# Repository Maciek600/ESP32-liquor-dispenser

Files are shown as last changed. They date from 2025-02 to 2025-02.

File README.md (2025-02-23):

# ESP32 Alcohol Dispenser with Scale
### The goal of the project was to create a beverage dispenser with a built-in scale that precisely controls the amount of liquid poured. The device automatically dispenses the user-specified amount of liquid, measured based on the weight of the cup or glass. The user places a glass on a base with an integrated scale (load cell). When the distance sensor detects the presence of a glass, the scale resets, and the user selects the desired amount of beverage using a control panel with buttons. After confirmation, the device automatically starts pouring, continuously monitoring the weight and precisely stopping the dispensing once the selected amount is reached. If no container is detected or the limit is reached, the system displays an appropriate message.

### The schematic and design were created using Autodesk Eagle. The code was written using Arduino IDE.

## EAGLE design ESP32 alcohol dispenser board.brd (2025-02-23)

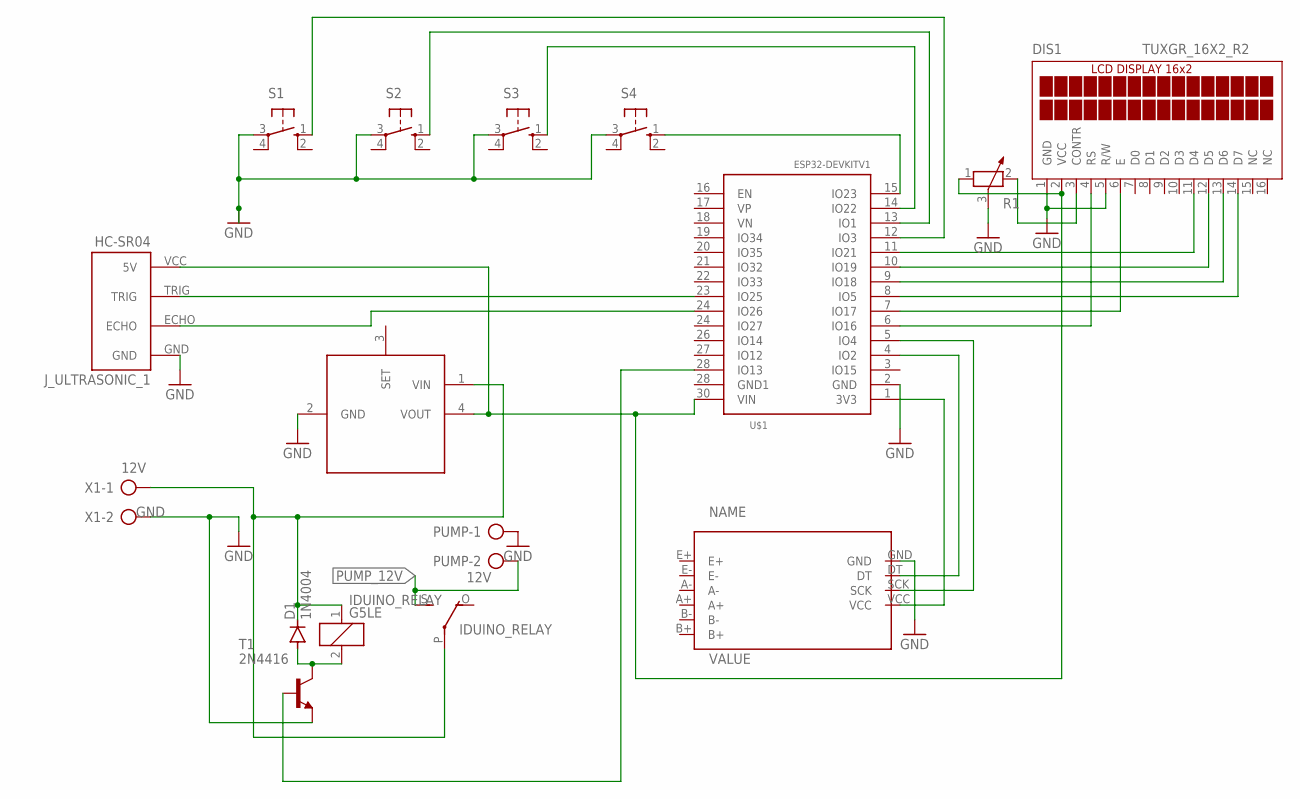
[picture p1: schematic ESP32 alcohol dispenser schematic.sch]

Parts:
D1: 1N4004; DO41-10
DIS1: TUXGR_16X2_R2
IDUINO_RELAY: G5LE
J_ULTRASONIC_1: HC-SR04; HC-SR04_FOOTPRINT
LM25965: LM2596S_MODULE; MOLEX-1X4_LOCK
PUMP: 12V; AK500/2-H
R1: POTENTIOMETER_PT-10; PT-10
S1, S2, S3, S4: 10-XX; B3F-10XX
T1: 2N4416; TO92
U$1: ESP32DEVKITV1; ESP32-DEVKITV1
U$3: HX711A; HX711
X1: AK300/2

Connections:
GND: DIS1.1 (GND), DIS1.5 (R/W), J_ULTRASONIC_1.GND, LM25965.2 (GND), PUMP.1, R1.3, S1.3, S2.3, S3.3, S4.3, T1.3 (E), U$1.2 (GND), U$3.GND, X1.2
unnamed: DIS1.6 (E), U$1.7 (IO17)
unnamed: T1.2 (B), U$1.28 (IO13)
unnamed: U$1.1 (3V3), U$3.VCC
unnamed: U$1.4 (IO2), U$3.DT
unnamed: U$1.5 (IO4), U$3.SCK
unnamed: J_ULTRASONIC_1.ECHO, U$1.24 (IO27)
unnamed: J_ULTRASONIC_1.TRIG, U$1.23 (IO25)
unnamed: S4.1 (S), U$1.15 (IO23)
unnamed: S3.1 (S), U$1.14 (IO22)
unnamed: S2.1 (S), U$1.13 (IO1)
unnamed: S1.1 (S), U$1.12 (IO3)
unnamed: D1.A, IDUINO_RELAY.2, T1.1 (C)
unnamed: DIS1.11 (D4), U$1.11 (IO21)
unnamed: DIS1.12 (D5), U$1.10 (IO19)
unnamed: DIS1.13 (D6), U$1.9 (IO18)
unnamed: DIS1.14 (D7), U$1.8 (IO5)
unnamed: DIS1.2 (VCC), J_ULTRASONIC_1.VCC (5V), LM25965.4 (VOUT), R1.1, U$1.30 (VIN)
unnamed: DIS1.4 (RS), U$1.6 (IO16)
unnamed: D1.C, IDUINO_RELAY.1, IDUINO_RELAY.P, LM25965.1 (VIN), X1.1
unnamed: DIS1.3 (CONTR), R1.2
PUMP_12V: IDUINO_RELAY.S, PUMP.2

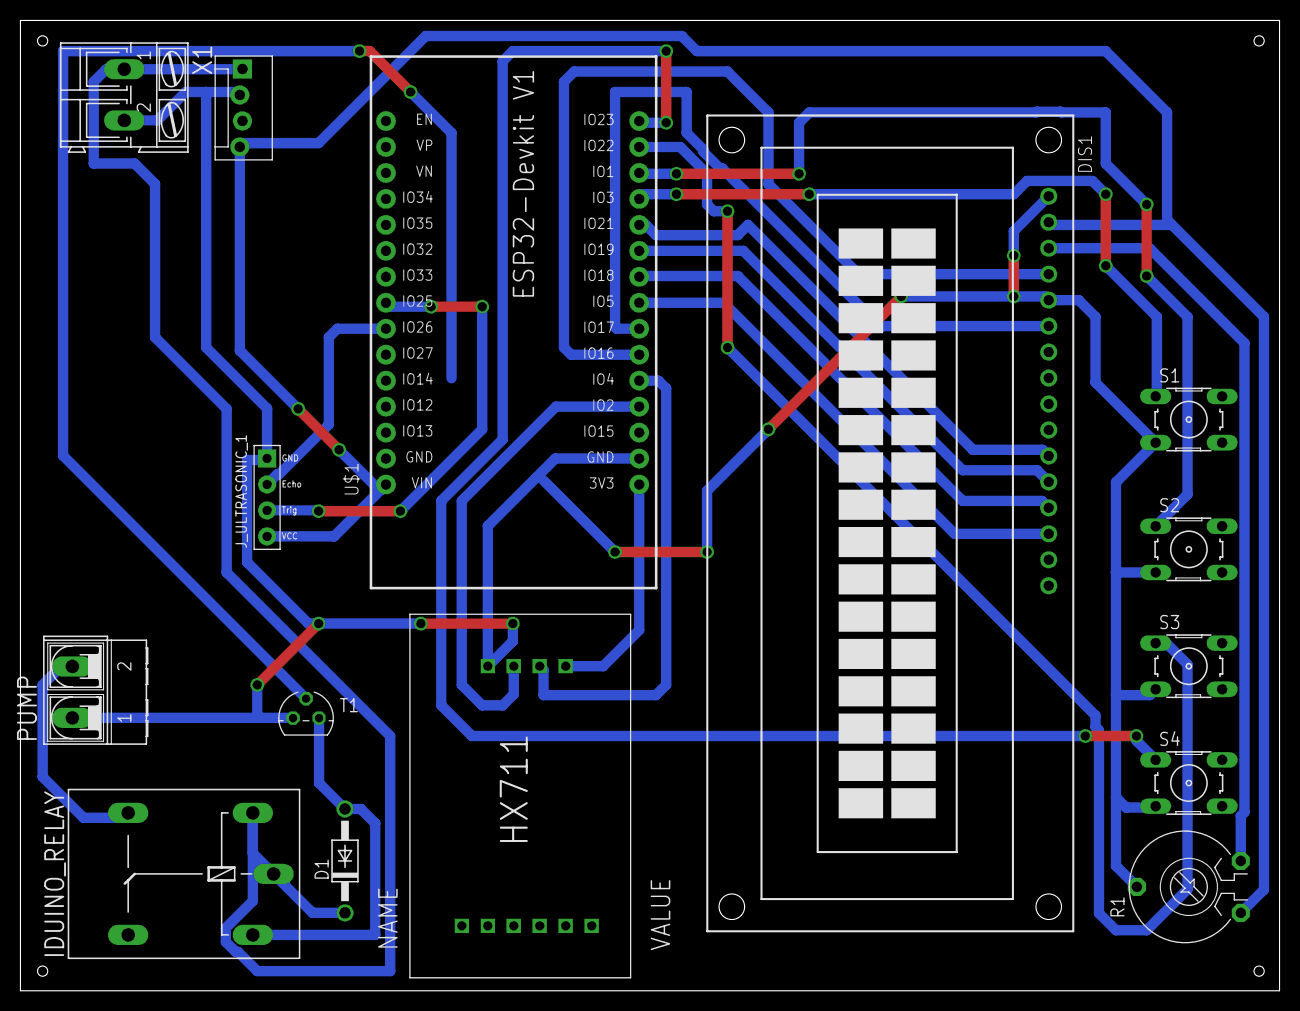
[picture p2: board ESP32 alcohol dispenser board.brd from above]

Board: 2 copper layers, 123.2 x 94.9 mm, 15 parts (0 on the bottom side), 22 nets.

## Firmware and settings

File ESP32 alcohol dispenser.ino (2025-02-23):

#include <LiquidCrystal.h>
#include "HX711.h"

// Piny do LCD
LiquidCrystal lcd(16, 17, 21, 19, 18, 5);

// Piny HC-SR04
#define TRIG_PIN 25
#define ECHO_PIN 26

// Piny przycisków
#define BUTTON_30ML 3
#define BUTTON_60ML 1
#define BUTTON_70ML 22
#define BUTTON_80ML 23

// Pompka
#define PUMP_PIN 13

// Belka tensometryczna
#define DT 2
#define SCK 4
HX711 scale;
float tara_waga;

void setup() {
    lcd.begin(16, 2);
    lcd.print("Poloz szklanke");

    pinMode(TRIG_PIN, OUTPUT);
    pinMode(ECHO_PIN, INPUT);
    pinMode(PUMP_PIN, OUTPUT);
    digitalWrite(PUMP_PIN, LOW);

    pinMode(BUTTON_30ML, INPUT_PULLUP);
    pinMode(BUTTON_60ML, INPUT_PULLUP);
    pinMode(BUTTON_70ML, INPUT_PULLUP);
    pinMode(BUTTON_80ML, INPUT_PULLUP);

    scale.begin(DT, SCK);
    scale.set_scale(401130.50 / 186.0);
    scale.tare();
}

float measureDistance() {
    digitalWrite(TRIG_PIN, LOW);
    delayMicroseconds(2);
    digitalWrite(TRIG_PIN, HIGH);
    delayMicroseconds(10);
    digitalWrite(TRIG_PIN, LOW);

    long duration = pulseIn(ECHO_PIN, HIGH);
    return duration * 0.034 / 2;
}

void pourLiquid(float targetWeight) {
    digitalWrite(PUMP_PIN, HIGH);
    while (abs(scale.get_units() - tara_waga) < targetWeight) {
        delay(100);
    }
    digitalWrite(PUMP_PIN, LOW);
    lcd.clear();
    lcd.print("Gotowe :)");
    delay(2000);
}

void loop() {
    float distance = measureDistance();
    if (distance > 5) {
        lcd.clear();
        lcd.print("Poloz szklanke");
    } else {
        delay(2000); // Odczekaj 2 sekundy przed tarowaniem
        scale.tare();
        tara_waga = scale.get_units();

        lcd.clear();
        lcd.print("Wybierz ml");
        lcd.setCursor(0, 1);
        lcd.print("30 60 70 80");

        while (true) {
            if (digitalRead(BUTTON_30ML) == LOW) {
                pourLiquid(30);
                break;
            } else if (digitalRead(BUTTON_60ML) == LOW) {
                pourLiquid(60);
                break;
            } else if (digitalRead(BUTTON_70ML) == LOW) {
                pourLiquid(70);
                break;
            } else if (digitalRead(BUTTON_80ML) == LOW) {
                pourLiquid(80);
                break;
            }
            delay(100);
        }
    }
    delay(500);
}
